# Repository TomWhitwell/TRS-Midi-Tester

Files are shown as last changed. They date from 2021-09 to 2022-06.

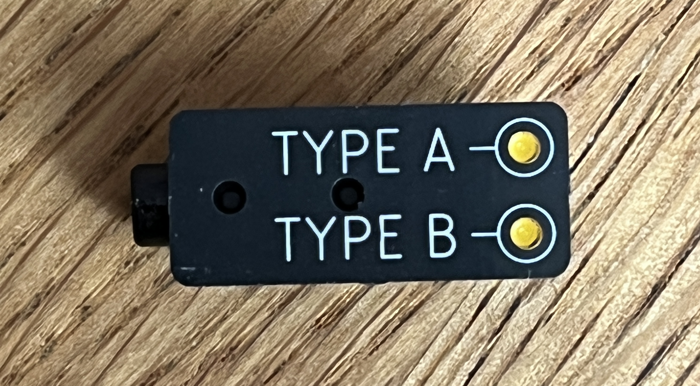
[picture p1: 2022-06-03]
images/front.jpg

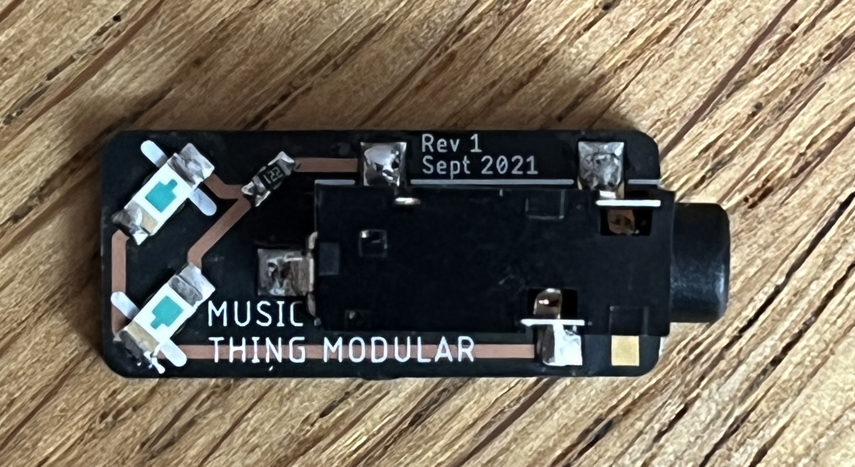
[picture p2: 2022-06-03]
images/back.jpg

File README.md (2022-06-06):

front

# Music Thing Modular TRS Midi Tester

A simple passive tester to identify if you TRS Midi signal is [Type A or Type B](https://minimidi.world/). 

3 x boards from Oshpark cost about $2. 

When building, ensure you get your LEDs the right way round!  

BOM: 

1 x 3.5mm Stereo SMD Audio Jack CUI SJ-3524-SMT-TR or equivalent  
1 x 330 Ohm 0603 resistor   
2 x 1206 LEDs suitable for reverse mounting KPTL-3216SYCK or similar (A 1206 LED with a circular / cylindrical lens - not a square lens - will fit into the hole.)  

back

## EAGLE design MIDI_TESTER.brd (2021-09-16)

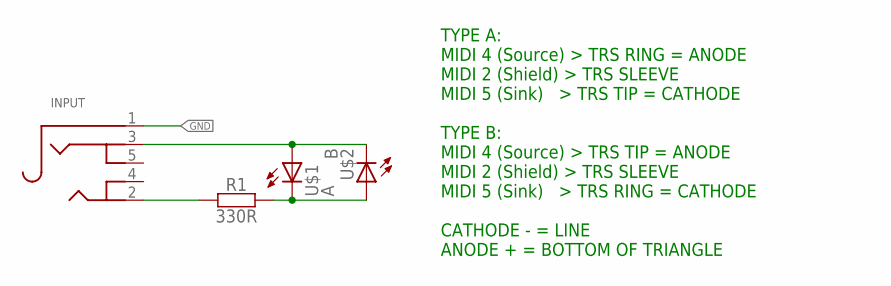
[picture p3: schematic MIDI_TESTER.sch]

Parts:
INPUT: AUDIO_3.5MMJACK; 4UCONN_19269
R1: 330R; C0603
U$1: A; LED-1206-REVERSE-PLATED
U$2: B; LED-1206-REVERSE-PLATED

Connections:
GND: INPUT.1
unnamed: INPUT.2, R1.1
unnamed: INPUT.3, U$1.A, U$2.C
unnamed: R1.2, U$1.C, U$2.A

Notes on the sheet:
TYPE A: MIDI 4 (Source) > TRS RING = ANODE MIDI 2 (Shield) > TRS SLEEVE MIDI 5 (Sink) > TRS TIP = CATHODE TYPE B: MIDI 4 (Source) > TRS TIP = ANODE MIDI 2 (Shield) > TRS SLEEVE MIDI 5 (Sink) > TRS RING = CATHODE CATHODE - = LINE ANODE + = BOTTOM OF TRIANGLE

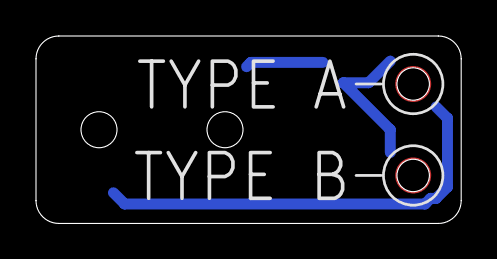
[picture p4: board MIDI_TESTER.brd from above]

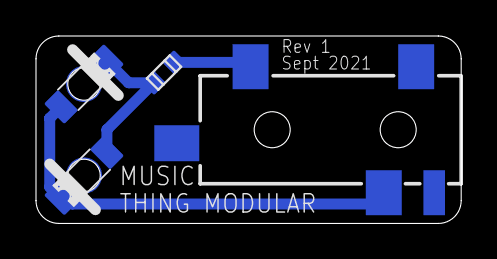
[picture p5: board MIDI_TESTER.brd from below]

Board: 2 copper layers, 23.6 x 10.4 mm, 4 parts (2 on the bottom side), 3 nets.

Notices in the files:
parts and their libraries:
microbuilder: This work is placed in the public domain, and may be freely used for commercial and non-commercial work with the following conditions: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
